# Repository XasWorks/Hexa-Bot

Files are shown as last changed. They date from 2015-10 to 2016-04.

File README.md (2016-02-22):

# Hexa-Bot

All required files, both .scad files for 3D Models aswell as the source files for the Arduino programming and the circuit plans for custom electronics (motor controller, special sensors, display etc.)

For documentation, see the "documentation" folder. Most importantly the scematics can be found under "KiCAD".

To program a robot, open Eclipse with working AVR Plugin, and "import existing project", with the folder being EclipseWS/Zephyr_Functional
The used PORTS can be changed inside the Code/System/Robot.h file.

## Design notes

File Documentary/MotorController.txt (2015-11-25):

Motor Controller Documentation: 

Chips used:
    - ATMega328 MCU
    - Pololu A4988 Stepper Motor Driver

I2C Interface Layout: 
    - Ground (Black)
    - SDA (White)
    - Vcc (Grey)
    - SCL (Purple)

Ground Connections: 
    + SPI Connector 
    + Quartz    
    + MCU
    + I2C
    + Battery Connector
    + Driver.0 
    + Driver.1 
    + Driver.2
    
Vcc Connections: 
    + SPI 
    + MCU
    + I2C
    + Motor Drivers

Other connections:
    + Vmot 
    + Crystal
    + SPI Interface
    + I2C 
    + Microstepping pins
    + Sensor pins
    + Motor Controllers to MCU

Wiring from the Mega8: 
    - PB3 & PB4 & PB5: SPI
    - PB6 & PB7: OSC (16MHz)
    - PC0 - PC3: Sensor Connectors
    - PC5 & PC4: I2C Interface
    - PC6: RESET
    - PD0 & PD1: Driver.0
    - PD2 & PD3: Driver.1
    - PD4 & PD5: Driver.2

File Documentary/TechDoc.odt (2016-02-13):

Technische Dokumentation des Roboters „Zephyr“ - RoboCup 2016

Teammitglieder: David Bailey, Felix Diekmann

Steuergerät:

Das Steuergerät des Roboters ist ein auf dem ATMega328-P basierendes, selbst gebautes Controller-Board. Der MCU läuft auf 16 Mhz, und wird mithilfe eines STK500v2 über SPI programmiert.

Ebenfalls auf dem Board befindlich ist ein 5v Spannungsregler zur Stromversorgung, Anschlüsse für vier Sensoren (analog/digital), sowie drei Pololu A4988 Stepper Motor Treiber zur Steuerung der Schrittmotoren, wobei das Microstepping über einige Schalter angepasst werden kann. Zusätzlich können weitere Module mithilfe von TWI (bzw. I2C) angeschlossen werden.

Sensorik:

Die Sensorik des Roboters besteht aus drei DFRobot SEN0017 Digital Line Tracking Sensoren, sowie einem Endstop Switch.

Die Line Tracking Sensoren wurden am vordere Ende des Roboters angebracht und dienen dem Line-Following. Sie sind direkt am Controller-Board angeschlossen, und liefern digitale Daten über das (nicht) vorhanden sein der Linie an der jeweiligen Position.

Der Endstop Switch ist oberhalb der Line Tracking Sensoren angebracht, und dient der Erkennung von Hindernissen, um diese umgehen zu können.

Aktuatorik:

Die Aktuatorik des Roboters besteht aus drei in 120° voneinander gedrehten Positionen angebrachten Schrittmotoren (2x Pololu 35x36mm, 2.7V, 1A / Phase, 1x Pololu 35x26mm, 7.4V, 0.28A / Phase), an denen eigens erstellte und 3D gedruckte Omni-Wheels angebracht wurden. Sie werden über die auf dem Controller-Board befindlichen Stepper Motor Controller mit Strom versorgt und gesteuert.

Als Motor für den Greifarm wird ein HobbyKing HK15148B Digital Servo verwendet.

Software:

Die Software für den ATMega328-P wurde komplett in C++ geschrieben, und verwendet ausschließlich eigene, speziell für den Roboter geschriebene Bibliotheken. Als IDE dient Eclipse Luna mit AVR Plugin, um kompilieren mit dem AVR-GCC Compiler zu ermöglichen. Als VCS dient Github ( https://www.github.com/Xasin/Hexa-Bot )

Die 3D-Modellierung aller Teile ist mit OpenSCAD geschehen. Auch hier wurde einzig selbst geschriebener Code verwendet.

Spezielle Hinweise:

Aktuatorik:

Die spezielle Aktuatorik des Roboters, bestehend aus den drei in 120°-Winkeln angeordneten Schrittmotoren, erlaubt für einen zentimetergenauen omnidirektionalen Antrieb. Dieser erlaubt es dem Roboter, sich komplett frei auf einer zweidimensionalen Oberfläche zu bewegen und sich problemlos zu Drehen, vorwärts/rückwärts und seitwärts zu fahren.

Dies macht das gesamte System sehr mobil und wendig, was viele Aufgaben, welche Präzision benötigen, einfacher gestaltet.

Software:

Um eine solche Bewegungsfreiheit voll ausnutzen zu können wurde die Software auf eine Art und Weise geschrieben, welches die Steuerung um ein vielfaches vereinfacht. Hierbei werden die einzelnen Schrittmotoren jeweils von einem eigenen Objekt angesteuert, welches über einen 5kHz ISR eine simple Geschwindigkeitssteuerung bietet und für einen ruhigen Lauf sorgt. Diese simplen Schrittmotor-Objekte werden von einer Controllsoftware mit ca. 150Hz angesteuert. Diese komplexere Software übernimmt die Berechnung von X und Y Geschwindigkeit um eine konstante lineare Geschwindigkeit zu realisieren, und speichert dabei die momentane Position ab, welche sie mit der Soll-Position vergleichen kann.

Dies erlaubt es dem Benutzer die Motoren durch simple Angabe von X und Y Koordinaten in Millimeter, bzw. Rotation in Grad zu steuern, sowie Geschwindigkeiten in mm/s und Grad/s ein zu stellen.

Zudem wurde der Code so flexibel wie möglich strukturiert. Objekte wurden, wenn möglich, verwendet.

So z.B. gibt es eine bestimmte Klasse, welche nur für die Verwertung der Line Tracking Sensoren verwendet wird. Sie basiert auf einer Base-Klasse, und wird lediglich durch Pointer in anderen Objekten und Funktionen verwendet. Dies erlaubt es, schnell und ohne viel Mühe einen anderen Sensortyp ein zu bauen. Lediglich ein anderes Objekt muss instanziert und übergeben werden.

Auch in der Main-Loop wird dort lediglich die Funktion eines Pointers zu einem bestimmtem Objektes ausgeführt. Dieser Pointer kann dann während einer ISR umgeändert werden, sodass nun ein anderer Code ausgeführt wird. Dies erlaubt eine sehr flexible und verständliche Struktur, da jede Funktion eine bestimmte Aufgabe übernehmen kann, ohne dabei andere Funktionen zu beeinflussen.

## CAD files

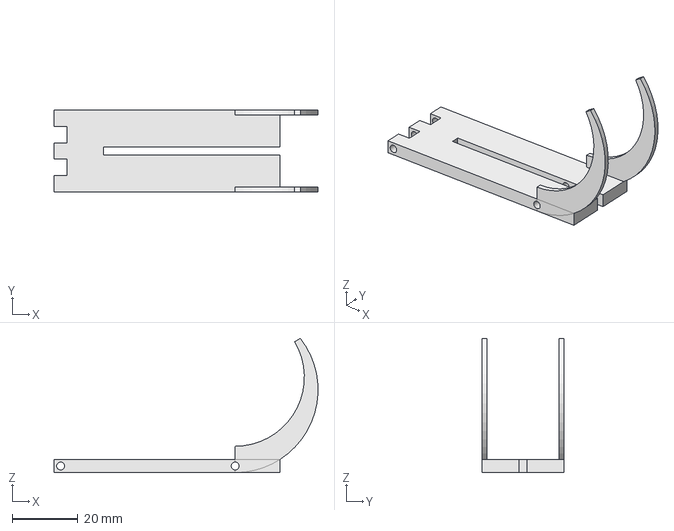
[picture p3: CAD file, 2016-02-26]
3DModels/GrabArm/MainArm.fcstd
80.1 x 25.0 x 40.7 mm

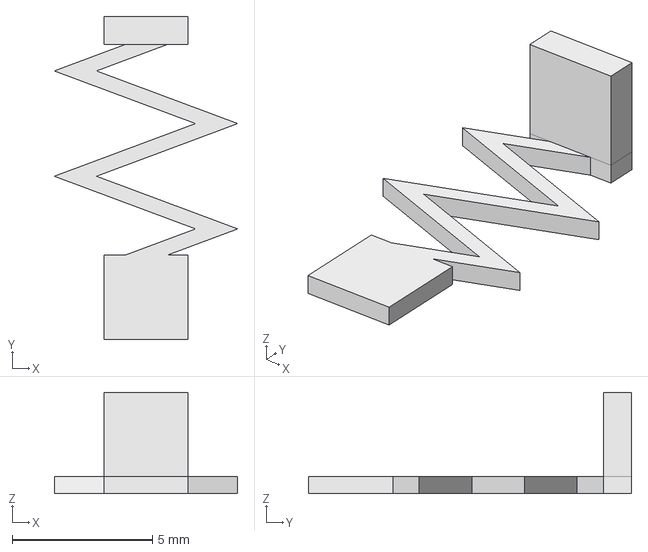
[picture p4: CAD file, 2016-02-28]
3DModels/GrabArm/MoveSpring.fcstd
6.53 x 11.5 x 3.60 mm

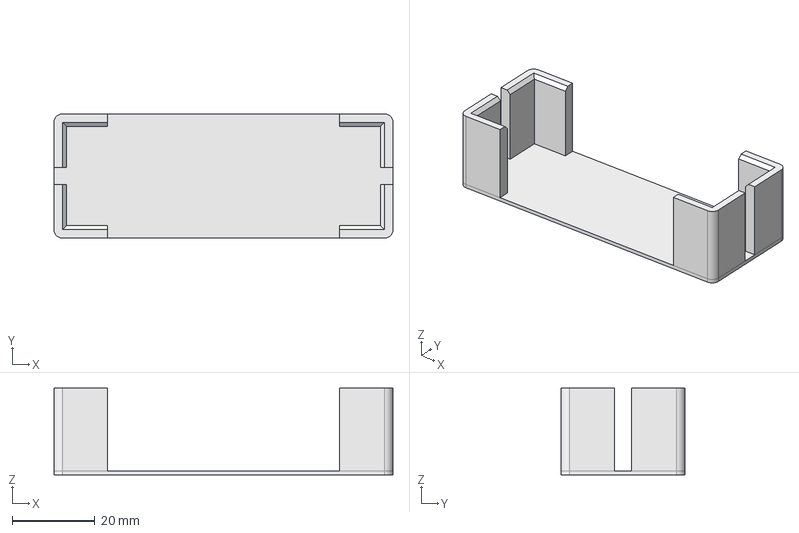
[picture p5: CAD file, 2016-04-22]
3DModels/HexGridSystem/BatteryHolder/BHolder.fcstd
82.0 x 30.0 x 21.0 mm

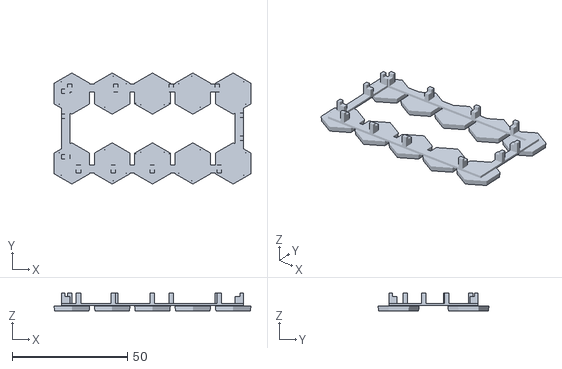
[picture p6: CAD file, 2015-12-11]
3DModels/STL/ControllerHolder.stl
85.5 x 48.2 x 7.75

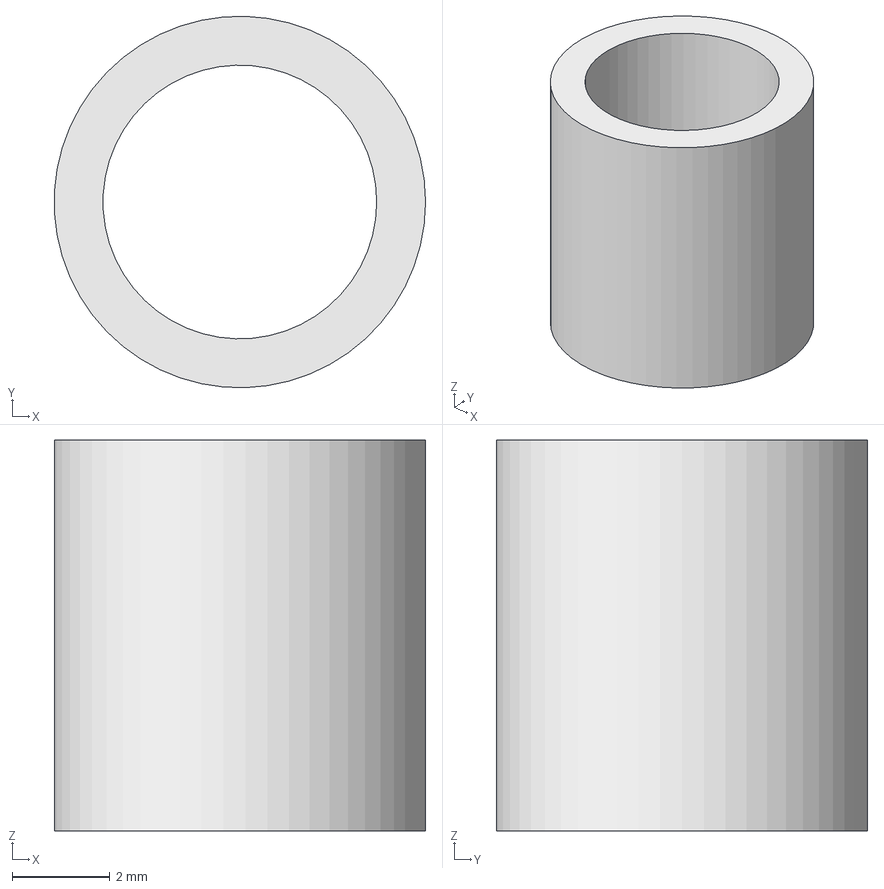
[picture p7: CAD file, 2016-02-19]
3DModels/Various/WheelDistancer.fcstd
7.59 x 7.60 x 8.00 mm

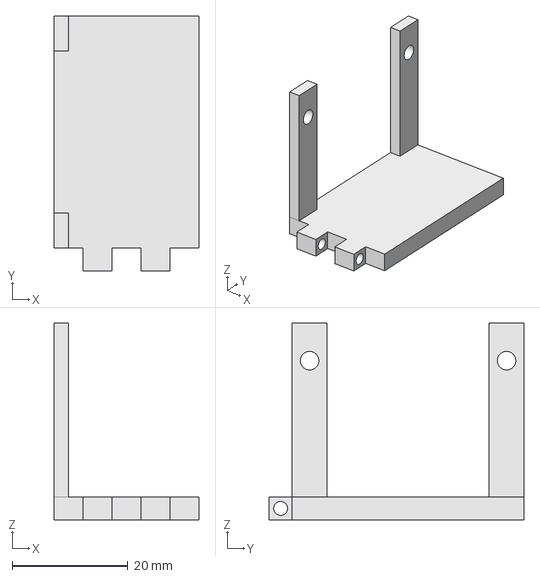
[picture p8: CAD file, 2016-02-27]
3DModels/GrabArm/Mountpoint.fcstd
25.0 x 44.0 x 34.0 mm

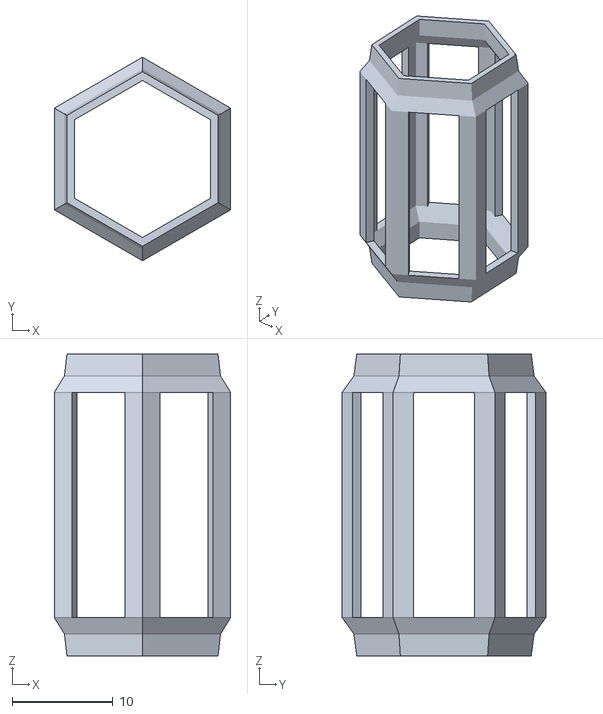
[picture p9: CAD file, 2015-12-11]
3DModels/STL/Distancer.stl
17.5 x 20.2 x 30.0

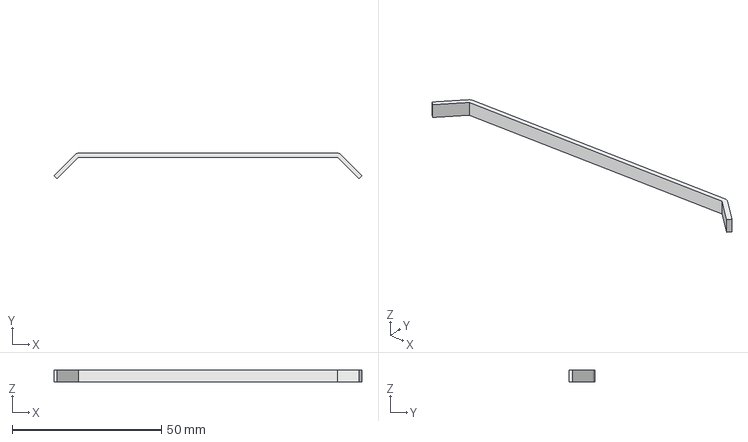
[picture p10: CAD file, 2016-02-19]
3DModels/Various/Bumper.fcstd
103.3 x 8.57 x 4.00 mm

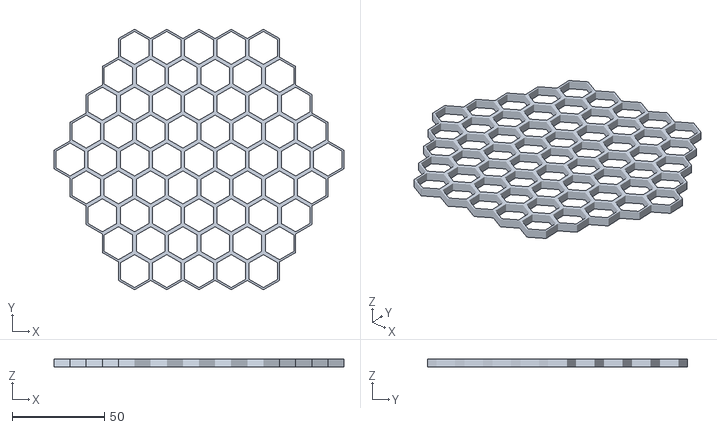
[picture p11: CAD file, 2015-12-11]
3DModels/STL/BasePlate.stl
157.5 x 141.5 x 4.40

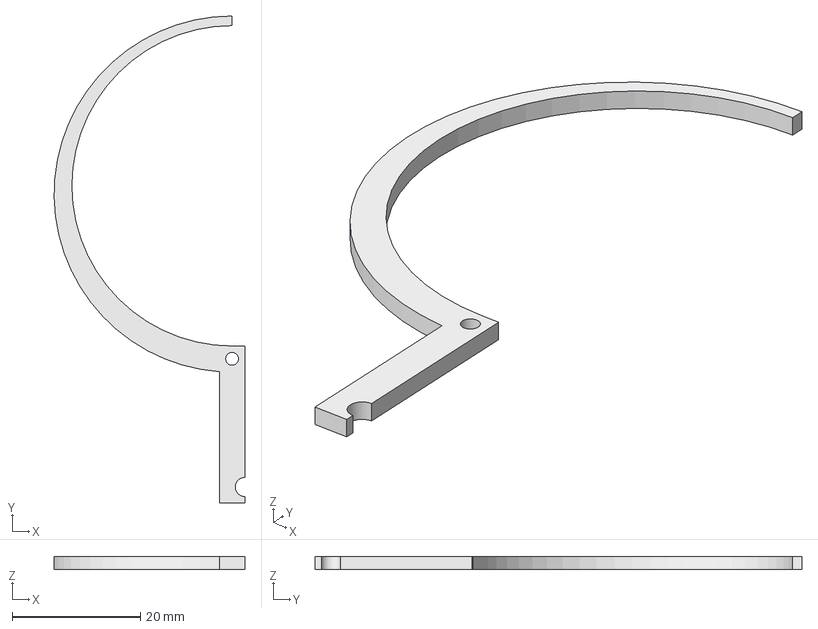
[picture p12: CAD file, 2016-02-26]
3DModels/GrabArm/MoveArm.fcstd
29.8 x 76.0 x 2.00 mm

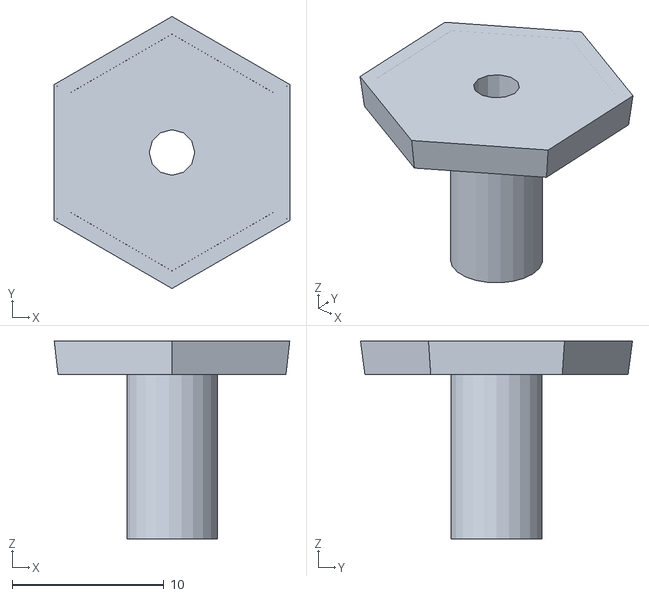
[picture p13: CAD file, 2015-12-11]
3DModels/STL/LF-Senor-Mount.stl
15.5 x 17.9 x 13.0

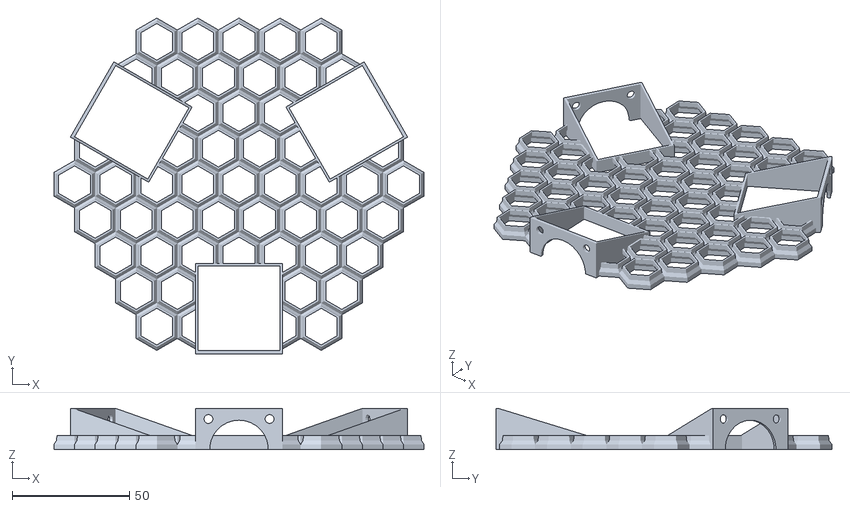
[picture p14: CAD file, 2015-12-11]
3DModels/STL/MotorPlate.stl
157.5 x 143.0 x 17.5

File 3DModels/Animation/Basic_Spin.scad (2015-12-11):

use <../Lib/Parenting.scad>
use <../Lib/HexGrid.scad>

//function linearSegmet(start, end, v1, v2) = if($t < start) v1 else if($t > end) v2 else (($t - start) / (end - start)) * (v2 -v1) + v1;
function linearSegmet(start, end, v1, v2) = ($t < start) ? (v1) : ( ($t > end) ? v2 : ( (($t - start) / (end - start)) * (v2 -v1) + v1 ));
function linearLift(start, end, v1, v2) = [[0, 0, linearSegmet(start, end, v1, v2)], 0];
function segmentedLift(n, i, v1, v2) = linearLift(i/n, (i+1)/n, v1, v2);

module electronicsMount() color("Orange"){
  translate([17.5/2, 0, 2.2 + 1]) import(file = "../STL/ControllerHolder.stl");
}

module basePlate() color("YellowGreen") {
  import(file = "../STL/BasePlate.stl");
}

top_layer_node = [[0, 0, 30 - 2.2], [0, 0, 0]];
module distancerModules() color("orange") {
  translate([0, 0, -3.8])
  for (i = [0:5]) {
    rotate([0, 0, 60*i])
    parentBy(hexNode([4, 0]))
    import(file = "../STL/Distancer.stl");
  }
}

module LF_Sensor() color("Orange") {
  translate([0, 0, -13 + 2.2]) import(file = "../STL/LF-Senor-Mount.stl");
}

module motorPlate() color("YellowGreen") {
  translate([0, 0, 6]) rotate([180, 0, 0]) import(file = "../STL/MotorPlate.stl");
}

splitDistance = $t * 4;

//Node for the robot's ground position
ground_node = [[0, 0, 0], [0, 0, 0]];

//Additional node for animation distancing
split_node = [[0, 0, splitDistance], [0, 0, 0]];

totalSegments = 3;

$vpr = [70, 0, linearSegmet(0, 1, 120, -5)];

parentBy(ground_node) {

  motorPlate();

  parentBy(hexNode([3, 1]) + linearLift(0, 0.3, 100, 0) ) LF_Sensor();
  parentBy(hexNode([2, 3]) + linearLift(0, 0.3, 100, 0) ) LF_Sensor();

  parentBy(hexNode([0,0])) {
    parentBy(linearLift(0.1, 0.4, 100, 0)) distancerModules();

    parentBy(top_layer_node) {
      parentBy(linearLift(0.2, 0.5, 100, 0)) basePlate();

      parentBy(hexNode([-1, -3], 2.2) + linearLift(0.3, 0.6, 100, 0)) electronicsMount();
    }
  }
}

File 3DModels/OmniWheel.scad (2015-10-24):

/*
	.scad file created for the subwheel system of the 3D Printable Omni-Wheels used for a robot.
	
	
	Author 	= Xasin
	Website = https://www.github.com/xasin/hexa-bot.git
	Created	= 17.09.15
*/

use <Transforms.scad>

function subwheelRadius(n, r) = r - cos(360/(2*n) + subwheelOverlap)*r + subwheelBaseSize;		//Calculate the radius of a standard subwheel at largest point (Center)
function wheelOffset(n, r) = cos(360/(2*n) + subwheelOverlap)*r;						//Calculate the offset of a subwheel that is required to shift it so that it aligns with the main circle (CAUTION Does not implement subwheel size shift!!)
function connectorOffset(n, r) = (sin(360/(2*n) + subwheelOverlap)*r);					//Calculate the offset for the cuts on the wheels. (Y axis on the 2D model of a subwheel before being rotated.
	
$fs = 0.5;

//What to generate - 1 means base frame, 2 means subwheel piece
generate = 1;

//GENERATION VARIABLES 
num = 5*2;	//Number of all subwheels to create. (Has to be a round number!!)
radius = 20;	//Radius of the omni-wheel.

//SUBWHEEL VARIABLES
subwheelBaseSize = 3.5;	//Size of the subwheels at their smallest point (The edge)
subwheelPlay = 0.5; 		//The additional size that will be cut out around the subwheels to ensure smooth movement
subwheelOverlap = 3;		//Angle in which the subwheel pieces will overlap. Causes smoother movement as there is no definite edge.

//AXIS HOLE VARIABLE
axisDiameter = 1.75;
axisPlay = 0.383;

//SUBWHEEL CONNECTOR VARIABLES
cRad = axisDiameter/2 + 1.5; 	//Radius of the connectors to the subwheels (Best is slightly smaller than the subwheel.
cThick = 0.8; 					//Thickness of the connectors.
cPlay = 0.2; 					//Play room for the connector ports (distance to the subwheel)

//FRAME VARIABLES
frameRadius = connectorOffset(num, radius) + cPlay + cThick;		//Radius of the frame Cylinder
frameHeight = cRad + subwheelRadius(num, radius);
frameThickness = 0.8;		//Thickness of the main frame

//STABILITY BEAM VARIABLES
beamThickness = 2.5; 		//Thickness of the stability beams
beamNum = 5;

//CONNECTOR VARIABLES
connectorThickness = 1;	//Thickness of the vertical connectors
connectorInShift = 0.4;		//Inwards shift of the vertical connector beams (for smoother connection)
connectorHeight = 2.5;		//Height of the connector pieces above the main frame.

module subwheelBase(n, r=20, p=0, shift = subwheelBaseSize, split=true, positioned=true) {  //The base structure of a Subwheel, basically a slice of a circle of the radius of the wheel, cut down to be rotated into a proper subwheel for a wheel of Radius R with N Subwheels.
	
	//Position the wheel according to the given parameters (Aling it to the outside of the main wheel and rotate it around into position p.)
	render(4) if(positioned) {
		//Rotate to the according outside position.
		rotate([0, 0, (360/n) * p])
		//Translate to the edge of the circle
		translate([ wheelOffset(n, r) - subwheelBaseSize, 0, 0])
		//Rotate into horizontal position
		rotate([-90, 0, 0]) 
		//The main core of the subwheel
		subwheelBase(n, r, p, shift, split, false);
	}
	//Generate a standard subwheel without moving it around.
	else {
		render(convexity=4) difference() {				//Render the subwheel and make it hollow.
			union() {
				rotate_extrude() difference() {		//Generate the main subwheel
					intersection() {					//2D Model for the basic subwheel
						translate([ - wheelOffset(n, r) + shift, 0]) circle(r=r, $fn = 70);		//Main circle	
						translate([0, - sin(360/(2*n) + subwheelOverlap)*r]) square(sin(360/(2*n) + subwheelOverlap)*r *2);			//Intersecting square to only have the desired part of the circle
					}	
						
				}
				translate([0, 0, - sin(360/(2*n) + subwheelOverlap)*r]) cylinder(r=shift, h= sin(360/(2*n) + subwheelOverlap)*r *2);	//Central cylinder inside for the axis.
			}
			
			if(split) {
				translate([0,0,-(sin(360/(2*n) + subwheelOverlap)*r)]) cylinder(d= axisDiameter + axisPlay*2, h= 2* sin(360/(2*n) + subwheelOverlap)*r,$fn=15);	//Slot for the Filament-Axis, rolling
			}
		}
	}
}

//Create the connecting beams for the subwheels
module subwheelConnector(n, r, i) {
	render(convexity = 3)
	rotate([0,0, (360/n)*i]) 
	difference() {				//The difference cuts the hole for the axis into the connectors
		intersection() {		//The intersection makes sure that the subwheel connectors don't poke outside of the wheel radius. This should not be nececary, but for smaller subwheel base sizes might be desirable.
			union() {		//The cylinders here are the end cylinders on either side of the connector, the cubes are the beams that connect those cylinders to the main frame.
				translate([wheelOffset(n, r) - subwheelBaseSize, connectorOffset(n, r) + cPlay + cThick]) rotate([90, 0, 0]) cylinder(r= cRad, h= cThick, $fn = 13);		
				
				translate([0, connectorOffset(n, r) + cPlay, -cRad]) 
					cube([wheelOffset(n, r) - subwheelBaseSize, cThick, cRad*2]);
				
				translate([wheelOffset(n, r) - subwheelBaseSize, -connectorOffset(n, r) - cPlay]) rotate([90, 0, 0]) cylinder(r= cRad, h= cThick, $fn = 13);
						
				translate([0, -connectorOffset(n, r) - cPlay - cThick, -cRad]) 
					cube([wheelOffset(n, r) - subwheelBaseSize, cThick, cRad*2]);
			}
			
			translate([0,0, -cRad]) cylinder(r=r - 0.3, h= cRad*2);
		}
		
		translate([wheelOffset(n, r) - subwheelBaseSize, connectorOffset(n, r) + 5, 0]) rotate([90,0,0]) cylinder(d= axisDiameter + 0.4, h= connectorOffset(n, r)*2 + 10, $fn=14);
	}
}

module connectorStrengthener(n, r, i) {
	rotate([0,0, 360/n * i]) translate([0,0, -cRad]) intersection() {
		cylinder(r=sqrt(pow(connectorOffset(n, r),2) + pow(wheelOffset(n, r) - subwheelBaseSize, 2)) + 0.6, h=0.8, $fn=75);
		translate([0,connectorOffset(n, r) + cPlay,0]) cube([r, r, 0.8]);
		rotate([0,0, 360/n*2]) translate([0,-(connectorOffset(n,r) + cPlay + r), 0]) cube([r,r, 0.8]);
	}
}

//Create a set of subwheels as they would be normally positioned. Inflated = true makes them bigger; useful for creating space around the wheels.
module subwheelSet(n, r, inflated=false) {
	for(i=[0:2:n]) { 	
		if(inflated) {		
			subwheelBase(n, r, i, shift = subwheelBaseSize + subwheelPlay, split=false);									//Create a /bigger/ subwheel in normal, ground position.
		}
		else {
			subwheelBase(n, r, i);									//Do the same as above, however using default subwheels instead of bigger subwheels here.
		}
	}
}

//Create a subwheel connector set for the according wheel of size r with n subwheels.
module connectorSet(n, r) {
	for(i=[0:2:n]) {
		subwheelConnector(n, r, i);
		connectorStrengthener(n, r, i);
	}
}

//Create the central cylinder piece.
module centralCylinder(n, r) {
	render(convexity = 4) translate([0,0, - cRad]) difference() {
		cylinder(r= frameRadius, h= frameHeight);		//Create the central cylinder.
		cylinder(r= frameRadius - frameThickness, h= frameHeight);	//Hollow it out
	}
}
		
//Create the pieces that connect the two Omniwheel pieces together
module interconnectorPiece(n, r) {
	difference() {
		shine(height= frameHeight + connectorHeight, angle=(360/n) - 0.5, length= r)
		//"Shine" is a custom function that cuts down an object to a specific angle
		union() {
			cylinder(r= frameRadius - 0.1, h= frameHeight);		//Cylinder piece to connect the connector to the main frame.
			cylinder(r= frameRadius - frameThickness - connectorInShift, h= frameHeight + connectorHeight);		//Cylinder piece for the actual interconnector. This one is slightly smaller due to printing imperfections, thusly making sure that the pieces fit together nicely.
		}
		cylinder(r= frameRadius - frameThickness - connectorThickness - connectorInShift, h= frameHeight + connectorHeight);		//Hollow the interconnection pieces out so that they have the correct thickness.
		
	}
}

//Create the interconnections between two wheel pieces
module interconnections(n, r) {
	render(convexity= 2) translate([0,0, -cRad])
		for(i=[0:(360/(n/2)):360]) 
			rotate([0,0, i + 360/n])											
			interconnectorPiece(n, r);	
}

//Create the structural beams inside the subwheel for better stability.
module structuralBeams() {
	render(convexity = 4) translate([0,0, -cRad]) intersection() {
		cylinder(r= frameRadius, h= cRad*2);		//Make sure that the structural beams don't poke out of the main frame.
		
		for(i=[0:360/beamNum:360]) 
			rotate([0,0, i + 360/beamNum/2]) translate([0, -beamThickness/2, 0]) cube([frameRadius, beamThickness, 1]);		//Create the beams.
	}
}

//The Mainframe of the OmniWheel
module omniWheel(n, r, subwheels = false) {
	difference() {  union() {
			//Central Cylinder 
			centralCylinder(n, r);
			
			//Cylinder Interconnections

			interconnections(n, r);
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

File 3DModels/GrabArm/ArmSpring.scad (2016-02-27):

springLength = 20;

mntpadLength = 5;


cube([10, springLength, 1]);

cube([10, mntpadLength, 2]);
translate([0, springLength - mntpadLength, 0]) cube([10, mntpadLength, 2]);

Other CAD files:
3DModels/GrabArm/BallSpacer.scad
3DModels/GrabArm/Mountpoint.scad
3DModels/GrabArm/Mountpoint.stl
3DModels/GrabArm/MoveSpring.scad
3DModels/GrabArm/TestArm.scad
3DModels/HexGrid.scad
3DModels/HexGridSystem/BasePlate.scad
3DModels/HexGridSystem/BatteryHolder/Base.scad
3DModels/HexGridSystem/BoopSensor.scad
3DModels/HexGridSystem/ControllerHolder.scad
3DModels/HexGridSystem/Distancer.scad
3DModels/HexGridSystem/GreyscaleHolder.scad
3DModels/HexGridSystem/IR-Dist-Mount.scad
3DModels/HexGridSystem/LF-Sensor-Mount.scad
3DModels/HexGridSystem/LF-Sensor-Shielding.scad
3DModels/HexGridSystem/MotorPlate.scad
3DModels/HexGridSystem/SensorControllerHolder.scad
3DModels/HexGridSystem/SensorMount.scad
3DModels/HexGridSystem/StepperMotorHolder.scad
3DModels/Motion/OmniWheel.scad
3DModels/NewHexGrid.scad
3DModels/STL/Animation.scad
3DModels/Various/BSensorShielding.scad
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

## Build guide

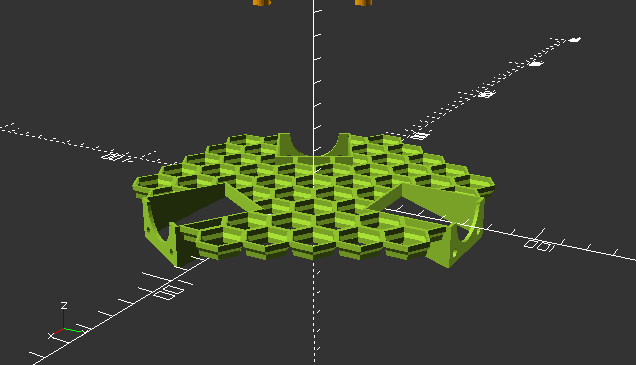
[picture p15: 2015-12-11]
3DModels/Animation/setup.gif

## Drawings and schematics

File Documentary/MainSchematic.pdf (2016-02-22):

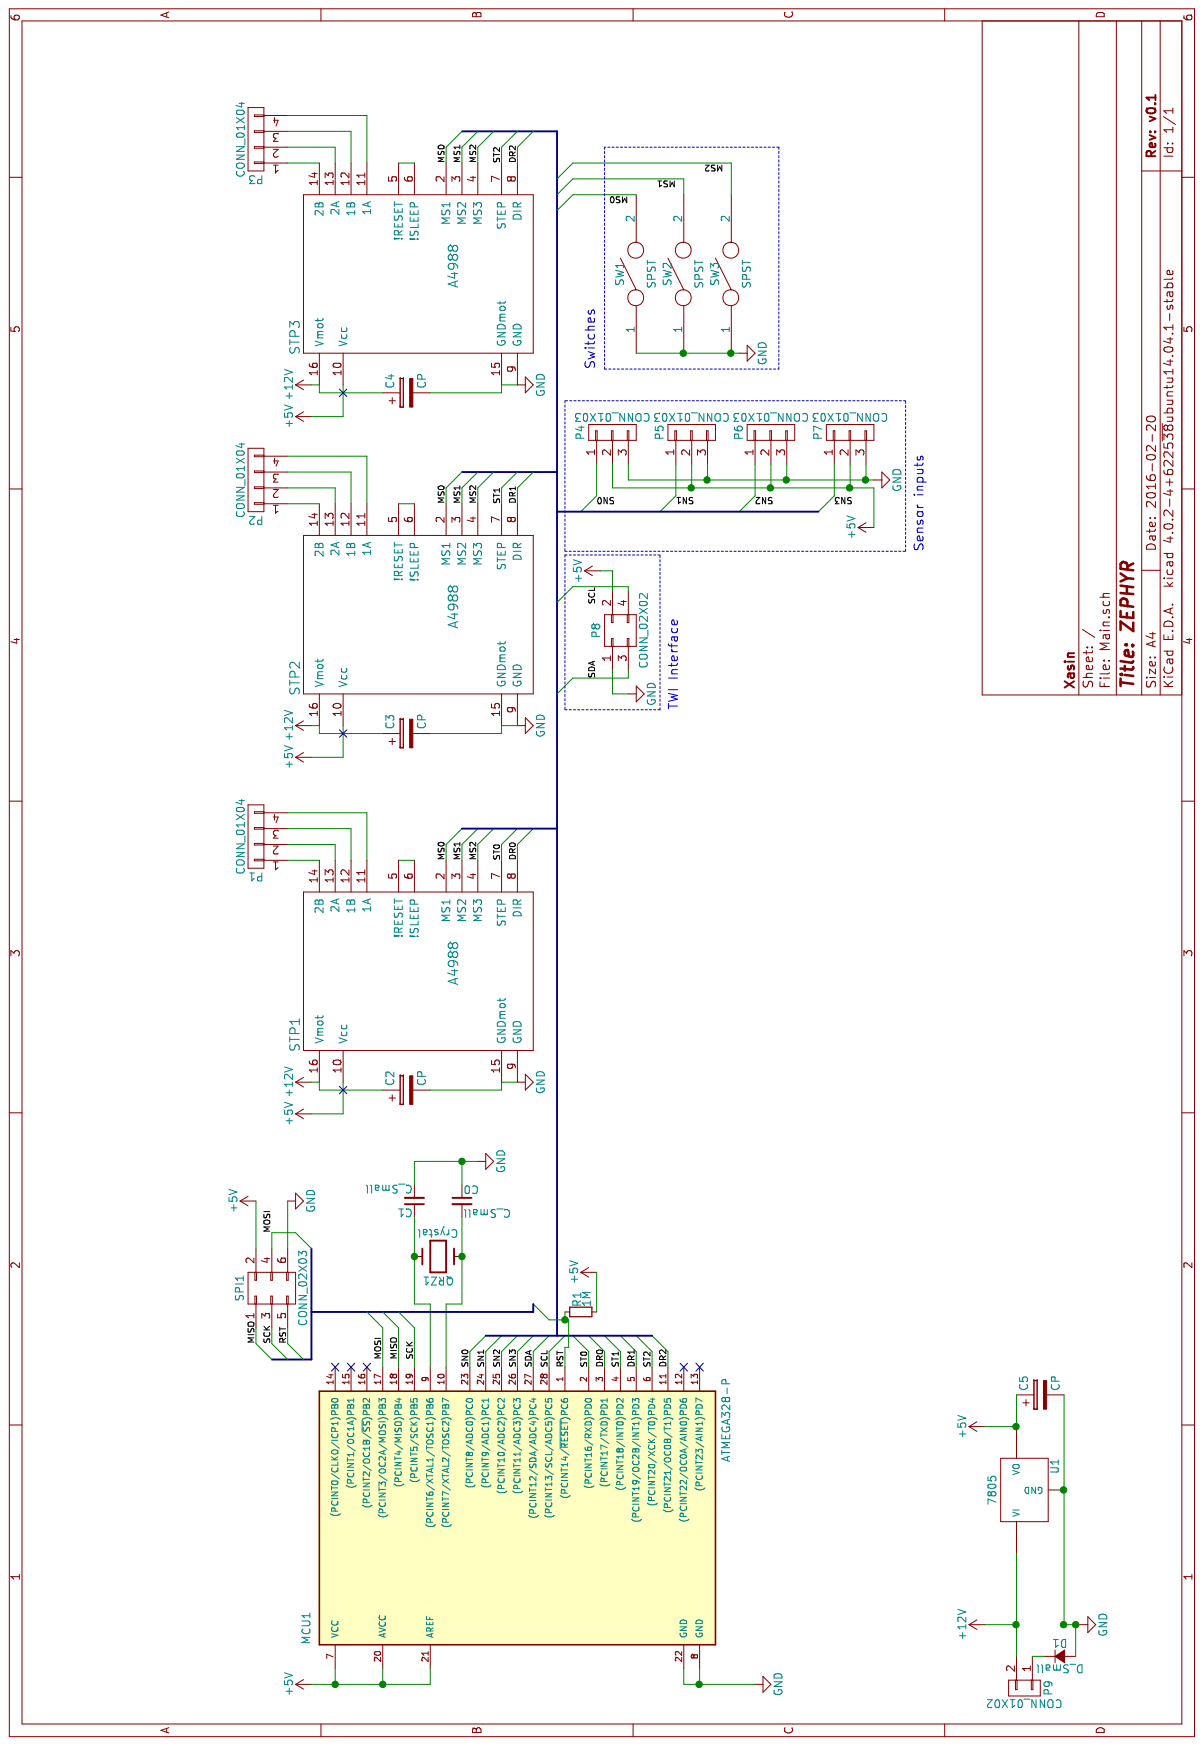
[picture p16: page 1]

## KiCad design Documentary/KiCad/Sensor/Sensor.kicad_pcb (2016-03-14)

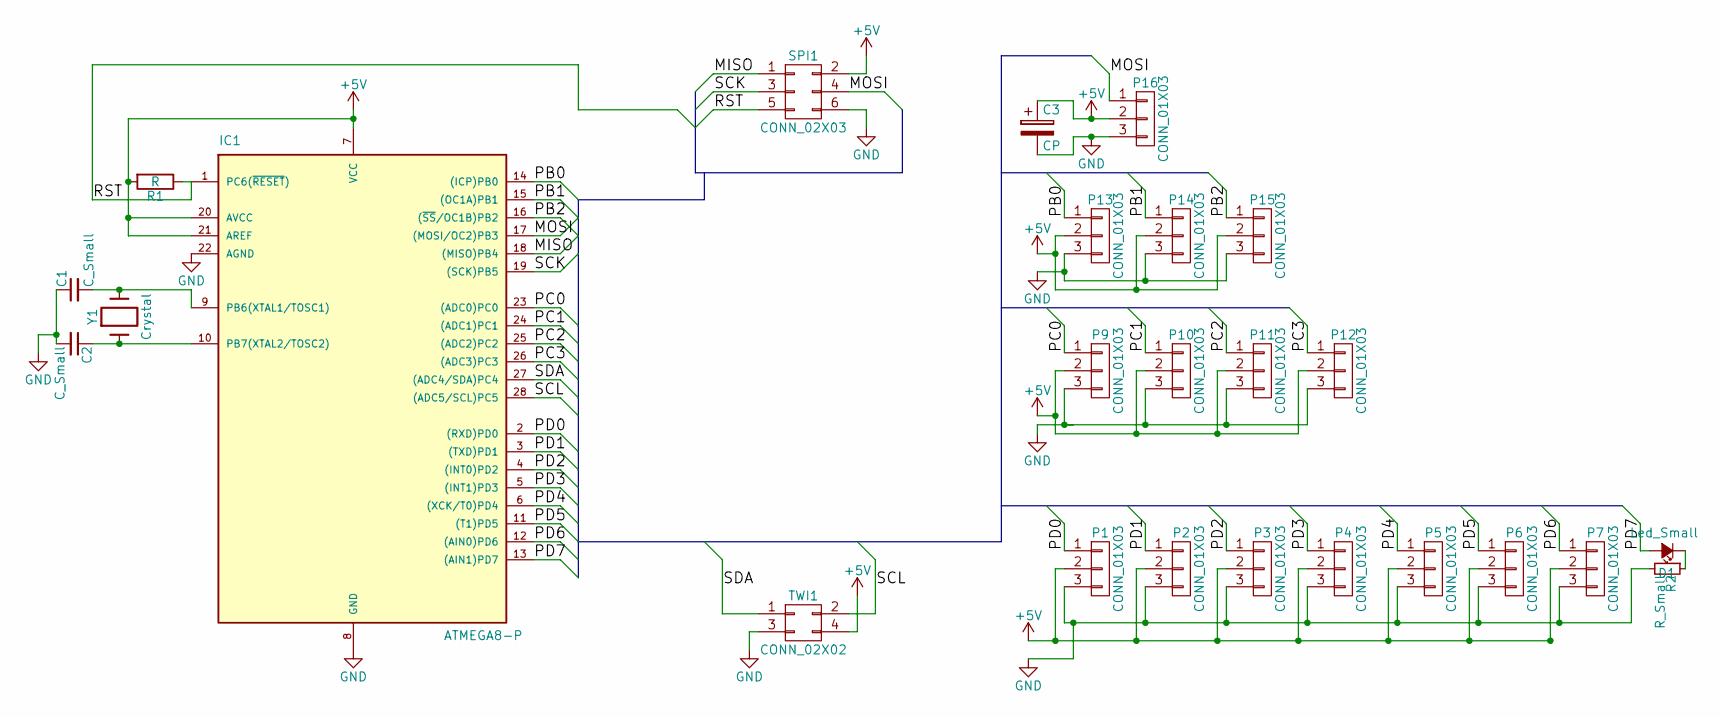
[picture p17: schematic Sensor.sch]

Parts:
C1, C2: C_Small; C_Disc_D3_P2.5
C3: CP; C1V8
D1: Led_Small; LED-3MM
IC1: ATMEGA8-P; DIP-28_W7.62mm
P1, P2, P3, P4, P5, P6, P7, P9, P10, P11, P12, P13, P14, P15, P16: CONN_01X03; Pin_Header_Straight_1x03
R1: R; R1
R2: R_Small; R1
SPI1: CONN_02X03; Pin_Header_Angled_2x03
TWI1: CONN_02X02; Pin_Header_Straight_2x02
Y1: Crystal; Crystal_HC52-U_Vertical

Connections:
+5V: C3.1, IC1.7 (VCC), IC1.20 (AVCC), IC1.21 (AREF), P1.2, P2.2, P3.2, P4.2, P5.2, P6.2, P7.2, P9.2, P10.2, P11.2, P12.2, P13.2, P14.2, P15.2, P16.2, R1.2, SPI1.2, TWI1.4
/MISO: IC1.18 ((MISO)PB4), SPI1.1
/MOSI: IC1.17 ((MOSI/OC2)PB3), P16.1, SPI1.4
/PB0: IC1.14 ((ICP)PB0), P13.1
/PB1: IC1.15 ((OC1A)PB1), P14.1
/PB2: IC1.16 ((~SS~/OC1B)PB2), P15.1
/PC0: IC1.23 ((ADC0)PC0), P9.1
/PC1: IC1.24 ((ADC1)PC1), P10.1
/PC2: IC1.25 ((ADC2)PC2), P11.1
/PC3: IC1.26 ((ADC3)PC3), P12.1
/PD0: IC1.2 ((RXD)PD0), P1.1
/PD1: IC1.3 ((TXD)PD1), P2.1
/PD2: IC1.4 ((INT0)PD2), P3.1
/PD3: IC1.5 ((INT1)PD3), P4.1
/PD4: IC1.6 ((XCK/T0)PD4), P5.1
/PD5: IC1.11 ((T1)PD5), P6.1
/PD6: IC1.12 ((AIN0)PD6), P7.1
/PD7: D1.2 (A), IC1.13 ((AIN1)PD7)
/RST: IC1.1 (PC6(~RESET~)), R1.1, SPI1.5
/SCK: IC1.19 ((SCK)PB5), SPI1.3
/SCL: IC1.28 ((ADC5/SCL)PC5), TWI1.2
/SDA: IC1.27 ((ADC4/SDA)PC4), TWI1.1
GND: C1.1, C2.2, C3.2, IC1.8 (GND), IC1.22 (AGND), P1.3, P2.3, P3.3, P4.3, P5.3, P6.3, P7.3, P9.3, P10.3, P11.3, P12.3, P13.3, P14.3, P15.3, P16.3, R2.2, SPI1.6, TWI1.3
unnamed: C1.2, IC1.9 (PB6(XTAL1/TOSC1)), Y1.2
unnamed: C2.1, IC1.10 (PB7(XTAL2/TOSC2)), Y1.1
unnamed: D1.1 (K), R2.1

Board: 2 copper layers, 25 parts (0 on the bottom side), 26 nets, no tracks yet.

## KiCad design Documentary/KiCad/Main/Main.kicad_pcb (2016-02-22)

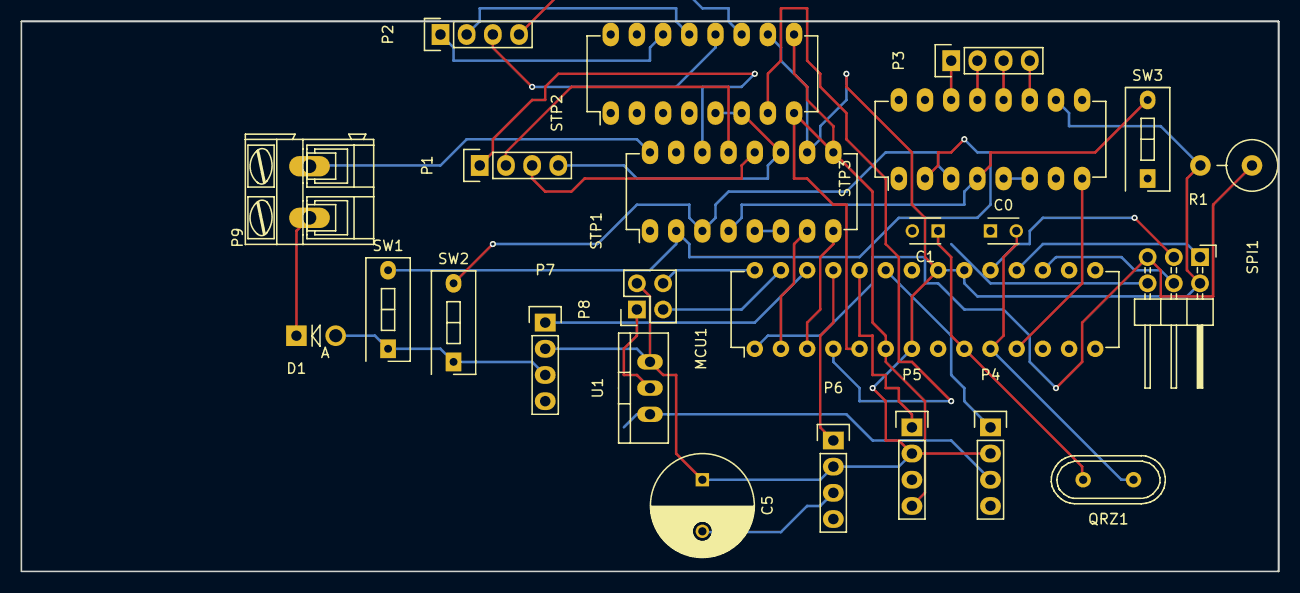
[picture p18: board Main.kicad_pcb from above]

Board: 32 copper layers, 121.9 x 53.3 mm, 24 parts (0 on the bottom side), 40 nets.

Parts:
C0, C1: C_Small; C_Disc_D3_P2.5
C5: CP; C_Radial_D10_L13_P5
D1: D_Small; Diode_DO-41_SOD81_Vertical_AnodeUp
MCU1: ATMEGA328-P; DIP-28_W7.62mm
P1, P2, P3: CONN_01X04; Pin_Header_Straight_1x04
P4, P5, P6, P7: CONN_01X03; Pin_Header_Straight_1x04
P8: CONN_02X02; Pin_Header_Straight_2x02
P9: CONN_01X02; AK300-2
QRZ1: Crystal; Crystal_HC49-U_Vertical
R1: 1M; Resistor_Vertical_RM5mm
SPI1: CONN_02X03; Pin_Header_Angled_2x03
STP1, STP2, STP3: A4988; DIP-16_W7.62mm_LongPads
SW1, SW2, SW3: SPST; SW_DIP_x1_Slide
U1: 7805; TO-220_Neutral123_Vertical

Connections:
+5V: C5.1, MCU1.7, MCU1.20, MCU1.21, P4.2, P5.2, P6.2, P7.2, P8.2, R1.2, SPI1.2, STP1.10, STP2.10, STP3.10, U1.3
+12V: P9.2, STP1.16, STP2.16, STP3.16, U1.1
/DR0: MCU1.3, STP1.8
/DR1: MCU1.5, STP2.8
/DR2: MCU1.11, STP3.8
/MISO: MCU1.18, SPI1.1
/MOSI: MCU1.17, SPI1.4
/MS0: STP1.2, STP2.2, STP3.2, SW1.2
/MS1: STP1.3, STP2.3, STP3.3, SW2.2
/MS2: STP1.4, STP2.4, STP3.4, SW3.2
/RST: MCU1.1, R1.1, SPI1.5
/SCK: MCU1.19, SPI1.3
/SCL: MCU1.28, P8.4
/SDA: MCU1.27, P8.3
/SN0: MCU1.23, P4.1
/SN1: MCU1.24, P5.1
/SN2: MCU1.25, P6.1
/SN3: MCU1.26, P7.1
/ST0: MCU1.2, STP1.7
/ST1: MCU1.4, STP2.7
/ST2: MCU1.6, STP3.7
GND: C0.1, C1.2, C5.2, D1.2, MCU1.8, MCU1.22, P4.3, P5.3, P6.3, P7.3, P8.1, SPI1.6, STP1.9, STP1.15, STP2.9, STP2.15, STP3.9, STP3.15, SW1.1, SW2.1, SW3.1, U1.2
unnamed: C0.2, MCU1.10, QRZ1.1
unnamed: C1.1, MCU1.9, QRZ1.2
unnamed: D1.1, P9.1
unnamed: P1.1, STP1.14
unnamed: P1.2, STP1.13
unnamed: P1.3, STP1.12
unnamed: P1.4, STP1.11
unnamed: P2.1, STP2.14
unnamed: P2.2, STP2.13
unnamed: P2.3, STP2.12
unnamed: P2.4, STP2.11
unnamed: P3.1, STP3.14
unnamed: P3.2, STP3.13
unnamed: P3.3, STP3.12
unnamed: P3.4, STP3.11
unnamed: STP1.5, STP1.6
unnamed: STP2.5, STP2.6
unnamed: STP3.5, STP3.6

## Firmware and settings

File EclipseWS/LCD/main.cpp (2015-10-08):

/*
 * main.cpp
 *
 *  Created on: Oct 3, 2015
 *      Author: xasin
 */

#include <avr/io.h>
#include <util/delay.h>
#include <avr/interrupt.h>
#include <math.h>

#include "Code/LCD.h"
#include "PWMLed.h"

LCD disp(&PORTA);			//Create a new display object for the system.

PWMLed light1(&PORTD, 3, 20);
PWMLed light2(&PORTD, 0, 200);


volatile uint32_t ms=0;		//Millisecond-Counter variable.

volatile uint8_t pwm1 = 0;	//PWM Variable (contains counter and upper limit)
volatile uint8_t trg1 = 0;	//PWM "target" (to switch LED on and off)

volatile uint8_t splitter=0;	//Variable for the software prescaler for the interrupt.

ISR(TIMER1_COMPA_vect) {
	disp.updateDisplay();
	if(ms != 0)
		ms++;

	light1.updatePWM();
	light2.updatePWM();
}


int main() {
	PORTB |= (1<<0 | 1<<1);

	TCCR1B |= ((1<< CS11) | (1<< CS10) | (1<< WGM12));
	OCR1A =	F_CPU/64/1000 -1;

	TIMSK1 |= (1<< OCIE1A);

	sei();

	disp.cursorMode(CURSOR_ON_BLINK);

	//State of the light. 0 means completely off, 1 means awake, 2 means asleep
	uint8_t lightState = 0;
	uint8_t oldPinState = PINB & (0b00000011);
	while(true) {
		if(oldPinState != (PINB & 0b00000011)) {
			oldPinState = PINB & 0b00000011;
			switch(lightState) {
			case 0:
				if((PINB & (1<<1)) == 0)
					lightState = 1;
			break;
			case 1:
				if((PINB & (1)) == 0) {
					light2.setPWM(10);
					light1.setPWM(0);

					if((PINB & (1<<1)) == 0) {
						lightState = 2;
						light2.setPWM(0);
					}
				}
				else {
					light2.setPWM(0);
					light1.setPWM(13);

					if((PINB & (1<<1)) == 0) {
						light1.setPWM(0);
						lightState = 0;
					}
				}
			break;

			case 2:
				if(((PINB & 1) != 0) || ((PINB & (1<<1)) == 0)) {
					lightState = 1;
				}
			}
		}
	}
}

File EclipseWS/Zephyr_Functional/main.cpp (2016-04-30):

#include <avr/io.h>
#include <avr/interrupt.h>
#include <util/atomic.h>
#include <util/delay.h>

#include "Code/ADC/ADC_Lib.h"

#include "Code/System/Robot.h"
#include "Code/LineFollow/LF3Sens.h"

#include "Code/TWI/TWIHandler.h"
#include "Code/TWI/TWIJob.h"

#include "Code/Modules/LFFollow.h"
#include "Code/Modules/Intersection.h"
#include "Code/Modules/ObjectAvoid.h"

#include "Module/BallFineGrab.h"

#include "ServoController.h"
#include "IRDistanceSensor.h"
#include "BrightnessSensor.h"

Robot System = Robot();
LF3Sens LFSensor = LF3Sens();

ServoController servo = ServoController();
IRDistanceSensor irdist = IRDistanceSensor();
BrightnessSensor brsens = BrightnessSensor();

using namespace Module;
LFFollow LFSys = LFFollow(&System, &LFSensor);
Intersection INTSECSys = Intersection(&System, &LFSensor);
ObjectAvoid AVDSys = ObjectAvoid(&System);

BallFineGrab GRABSys = BallFineGrab(&System, &irdist, &servo);

Basic *cModule;

ISR(TWI_vect) {
	TWI_Handler::IO.update();
}

ISR(TIMER1_COMPA_vect) {
	System.update();

	LFSensor.update();
}

#define TASK_LF 	0
#define TASK_INTSEC 1
#define TASK_OBJ 	2

uint8_t currentTask = TASK_LF;

void setTask() {
	switch(currentTask) {
		// -- STANDARD LF --
		case TASK_LF:

			// Switch to object avoidance mode
			if((PINC & (1<< 3)) == 0) {
				irdist.updateWaiting();
				AVDSys.distance = irdist.get_distance();
				AVDSys.execute();
			}

			// Else, switch to Intersection mode
			else if ((LFSensor.lineStatus == LF_INTSEC)) {
				currentTask = TASK_INTSEC;
				cModule = &INTSECSys;
			}


		break;

		// -- INTERSECTION HANDLING --
		case TASK_INTSEC:
			currentTask = TASK_LF;
			cModule = &LFSys;
		break;

		// -- OBJECT HANDLING --
		case TASK_OBJ:
			currentTask = TASK_LF;
			cModule = &LFSys;
		break;
		}
}

int main() {

	// Pull-Ups for the TWI system
	PORTC |= (0b11 << 4);

	cModule = &LFSys;

	System.Motor.setRotationSpeed(50);

	servo.setServo(255);

	_delay_ms(500);

	while(true) {
		setTask();

		cModule->execute();
	}

	return 0;
}

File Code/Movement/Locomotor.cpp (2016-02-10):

/*
 * Locomotor.cpp
 *
 *  Created on: Nov 11, 2015
 *      Author: xasin
 */

#include "Locomotor.h"
#include <util/delay.h>

//Constructor of the Locomotor object
Locomotor::Locomotor(TranslativeStepper *A, TranslativeStepper *B,
		TranslativeStepper *C, uint16_t ISRFreq) {
	this->A = A;
	this->B = B;
	this->C = C;

	this->ISRFreq = ISRFreq;

}

//Recalculate X and Y speed factors.
void Locomotor::recalculateXYFact() {
	ATOMIC_BLOCK(ATOMIC_FORCEON)
	{
		float travelMM = sqrt(
				pow((this->xTarget - this->xPos), 2)
						+ pow(this->yTarget - this->yPos, 2)); //Calculate the distance the robot has to travel.

						//Calculate the X and Y factors (basically sinus and cosinus values for current direction of travel)
		this->xFact = ((this->xTarget - this->xPos) / travelMM);
		this->yFact = ((this->yTarget - this->yPos) / travelMM);
	}
}

void Locomotor::setRotationSpeed(float newSpeed) {
	ATOMIC_BLOCK(ATOMIC_FORCEON)
	{
		this->rPerISR = fabs(newSpeed) / this->ISRFreq;
	}
}

void Locomotor::setSpeed(float newSpeed) {
	ATOMIC_BLOCK(ATOMIC_FORCEON)
	{
		if (newSpeed > 1) {
			this->speedTarget = newSpeed / ISRFreq;
		}
	}
}

void Locomotor::setAcceleration(float acceleration) {
	ATOMIC_BLOCK(ATOMIC_FORCEON)
	{
		if (acceleration > 0)
			this->acceleration = acceleration / ISRFreq / ISRFreq;
	}
}

void Locomotor::moveTo(float x, float y) {
	ATOMIC_BLOCK(ATOMIC_FORCEON)
	{
		this->xTarget = x;
		this->yTarget = y;

		this->recalculateXYFact();
	}
}

void Locomotor::moveBy(float x, float y) {
	ATOMIC_BLOCK(ATOMIC_FORCEON)
	{
		this->xTarget += x;
		this->yTarget += y;

		this->recalculateXYFact();
	}
}

void Locomotor::moveTowards(float dist) {
		this->moveTowards(dist, this->rPos);
}

void Locomotor::moveTowards(float dist, float dir) {
	ATOMIC_BLOCK(ATOMIC_FORCEON)
	{
		this->xTarget += dist * cos(dir * DEG_TO_RAD);
		this->yTarget += dist * sin(dir * DEG_TO_RAD);

		this->recalculateXYFact();
	}
}

void Locomotor::flush() {
	do {
		_delay_ms(10);
	} while (!this->isReady());
}

void Locomotor::update() {

	//Pre-Calculate the Sin and Cos values for the current INVERSE Rotation!!
	float cSin = sin(-1 * this->rPos * DEG_TO_RAD);
	float cCos = cos(-1 * this->rPos * DEG_TO_RAD);

	//Calculate the steps that the motors will have to do this calculation. CAUTION - X and Y Motor axis do not aling with the Robot's current X and Y Axis!
	float xDifference = this->xTarget - this->xPos;
	float yDifference = this->yTarget - this->yPos;
	float rDifference = this->rTarget - this->rPos;
	float speedDiff = this->speedTarget - this->speed; //Calculate the speed difference (target to current speed)

	//How much will the robot have to move each calculation?
	float xThisISR = 0;
	float yThisISR = 0;
	float rThisISR = 0;

	/* --- Basic explanation of the calculation ---
	 * if the motor has to do any movement in the specified direction
	 * Calculate how much movement it will have to do in this ISR. This is either the currently set speed, calculated from the Axis-Speed-Factor and current robot speed,
	 * or the remaining distance between target and current position, whatever is smaller.
	 * Then increase (or decrease) the current position by the amount of mm that the robot will move this ISR.
	 */

	//Speed recalcultion
	if (speedDiff != 0)
		this->speed += (
				(fabs(speedDiff) > this->acceleration) ?
						((speedDiff > 0) ?
								this->acceleration : -this->acceleration) :
						speedDiff);

	//X-Steps calculation
	if (xDifference != 0) {
		xThisISR =
				(fabs(xDifference) > fabs(this->xFact * speed)) ?
						xFact * speed : xDifference;
		this->xPos += xThisISR;
	}

	//Y-Steps calculation
	if (yDifference != 0) {
		yThisISR =
				(fabs(yDifference) > fabs(this->yFact * speed)) ?
						yFact * speed : yDifference;
		this->yPos += yThisISR;
	}

	//Rotation-Stepping calculation
	if (rDifference != 0) {
		rThisISR =
				(fabs(rDifference) > fabs(this->rPerISR)) ?
						((rDifference < 0) ? -rPerISR : rPerISR) : rDifference;
		this->rPos += rThisISR;
	}

	//Rotate the movement axis.
	//As mentioned before, this is due to the ROBOT AXIS != MOTOR-RELATIVE AXIS
	float xRotated = cCos * xThisISR - cSin * yThisISR;
	float yRotated = cSin * xThisISR + cCos * yThisISR;

	A->stepBy(xRotated, yRotated, rThisISR);
	B->stepBy(xRotated, yRotated, rThisISR);
	C->stepBy(xRotated, yRotated, rThisISR);

	//Reset acceleration if at target and not having received a new command for ACCEL_DEBOUNCE_CYCLES updates
	if (this->atPosition()) {
		if (accelDebounce == 0)
			this->speed = 0;
		else
			accelDebounce--;
	} else
		accelDebounce = ACCEL_DEBOUNCE_CYCLES;

	//Make sure the rotation values do not get too high
	if (this->rPos > 360) {
		this->rPos -= 360;
		this->rTarget -= 360;
	}
	else if(this->rPos < -360) {
		this->rPos += 360;
		this->rTarget += 360;
	}
}

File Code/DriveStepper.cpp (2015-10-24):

/*
 * DriveStepper.cpp
 *
 *  Created on: 08.10.2015
 *      Author: xasin
 */

#include "DriveStepper.h"
#include <util/delay.h>

DriveStepper::DriveStepper(volatile uint8_t *P, uint8_t pin,
		uint16_t updateFrequency, uint16_t calculationFrequency,
		float stepsPerMM, float motorOffset, float localRotation) {
	ATOMIC_BLOCK(ATOMIC_FORCEON)
	{
		//Initialize all the values.
		this->PORT = P;
		this->pin = pin;
		this->updateFrequency = updateFrequency;
		this->ISRPerCal = updateFrequency / calculationFrequency;
		this->stepsPerMM = stepsPerMM;
		this->motorOffset = motorOffset;
		this->localRotation = localRotation;

		//Enable output mode
		*(PORT - 1) |= (0b11 << pin);

		//Set absolute position values to 0.
		currentRotation = 0;
		currentX = 0;
		currentY = 0;

		//Set the software prescaler value to 0.
		calculationDivider = 0;
	}
}

void DriveStepper::recalSinCos(float angle) {
	if (angle != oldAngle) {
		currentSin = sin(angle);
		currentCos = cos(angle);

		oldAngle = angle;
	}
}

void DriveStepper::recalculate() {
	//Software prescaler
	if (++calculationDivider == ISRPerCal) {
		calculationDivider = 0;

		if (currentX != targetX) {
			if (fabs(targetX - currentX) >= fabs(xPerCal)) {
				recalSinCos((currentRotation + localRotation) * DEG_TO_RAD);

				/*//Step the motor by the according amount.*/
				stepsToGo += currentSin * xPerCal * stepsPerMM;

				//Shift the current position by what we will move.
				currentX += xPerCal;
			} else {
				stepsToGo += currentSin * (targetX - currentX) * stepsPerMM;

				currentX = targetX;
			}
		}

		if (currentY != targetY) {
			recalSinCos((currentRotation + localRotation) * DEG_TO_RAD);
			if (fabs(targetY - currentY) >= fabs(yPerCal)) {

				stepsToGo += currentCos * yPerCal * stepsPerMM;

				currentY += yPerCal;
			} else {
				stepsToGo += currentCos * (targetY - currentY) * stepsPerMM;

				currentY = targetY;
			}
		}

		stepSpeed = fabs(stepsToGo / (ISRPerCal));
	} else if (calculationDivider == ISRPerCal / 2) {

		if (fabs(targetRotation - currentRotation) >= fabs(degPerCal)) {
			if ((targetRotation - currentRotation) < 0) {
				currentRotation -= degPerCal;

				stepsToGo -= motorOffset * (degPerCal * DEG_TO_RAD)
						* stepsPerMM;
			} else {
				currentRotation += degPerCal;

				stepsToGo += motorOffset * (degPerCal * DEG_TO_RAD)
						* stepsPerMM;
			}
		}

		stepSpeed = fabs(stepsToGo / (ISRPerCal));
	}
}

void DriveStepper::moveXYBy(float X, float Y) {
	float totalMM = sqrt(pow(X, 2) + pow(Y, 2));

	ATOMIC_BLOCK(ATOMIC_FORCEON)
	{
		targetX += X;
		targetY += Y;
		xPerCal = X / ((totalMM / mmPerSec) * (updateFrequency / ISRPerCal));
		yPerCal = Y / ((totalMM / mmPerSec) * (updateFrequency / ISRPerCal));
	}
}

void DriveStepper::moveXYTo(float X, float Y) {
	float totalMM = sqrt(pow((currentX - X), 2) + pow(currentY - Y, 2));

	ATOMIC_BLOCK(ATOMIC_FORCEON)
	{
		targetX = X;
		targetY = Y;
		xPerCal = X / ((totalMM / mmPerSec) * (updateFrequency / ISRPerCal));
		yPerCal = Y / ((totalMM / mmPerSec) * (updateFrequency / ISRPerCal));
	}
}

void DriveStepper::rotateTo(float angle) {
	ATOMIC_BLOCK(ATOMIC_FORCEON)
	{
		this->targetRotation = angle;
	}
}

void DriveStepper::rotateBy(float angle) {
	ATOMIC_BLOCK(ATOMIC_FORCEON)
	{
		this->targetRotation += angle;
	}
}

void DriveStepper::finishRotation() {
	while ((currentRotation - targetRotation) != 0) {
		_delay_ms(1);
	}
}

void DriveStepper::finishMovement() {
	while ((currentX - targetX) != 0 || (currentY - targetY) != 0) {
		_delay_ms(1);
	}
}

void DriveStepper::finishAll() {
	finishMovement();
	finishRotation();
}

void DriveStepper::setRotationSpeed(float degPerSec) {
	ATOMIC_BLOCK(ATOMIC_FORCEON)
	{
		this->degPerCal = degPerSec / (updateFrequency / ISRPerCal);
	}
}

void DriveStepper::setMovementSpeed(float mmPerSec) {
	ATOMIC_BLOCK(ATOMIC_FORCEON)
	{
		this->mmPerSec = mmPerSec;
	}
}

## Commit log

2010-01-01 Changed drive preference to move along right, not left.
    [Main.sch]
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2015-09-16 First Github Repo Push!! Oh, and added a README.
    [HexGrid.scad]
2015-09-16 There we go. Actual Commit, including all the files (instead of empty push *sigh*)
    [HexGrid.scad, HexGrid.stl]
2015-09-16 Moved the OpenSCAD "Transforms.scad" Library into the repo.
    [HexGrid.scad, Transforms.scad]
2015-09-16 Removed that one weird HexGrid.scad directly in the master directory. Why.
    [HexGrid.scad]
2015-09-17 Added the first (and hopefully last) version of the .scad file used for creating the subwheels of a Omni-wheel. All functions are commented, no need for later commenting.
    [OmniWheel.scad]
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2015-09-17 Fine-tuned the Filament-Axis holes.
    Values are now: 2.25 for tight-fitting and 2.4 for loosely-fitting.
    [OmniWheel.scad]
2015-09-17 Finalised the wheels. Fixes #1
    [OmniWheel.scad]
2015-09-18 Fixed the center piece of the OmniWheels.
    It not resizes properly, making itself fit nicely.
    Recommended wheel sizes: 20mm, 4 pieces or 30mm with 5 pieces
    [OmniWheel.scad]
2015-09-19 Filament axis hole now is only tighter towards end of the wheel.
    This should make it much more easy to insert the filament and fix the wheels in place. Glue is still recommended.
    Also, the hole diameter now is designed for toothpicks!!!
    [OmniWheel.scad]
2015-09-19 Fine-tuned axis-hole-size
    Small improvements, nothing worth mentioning for now.
    [OmniWheel.scad]
2015-09-20 Optimised and changed a few things.
    Nothing worth noting, mostly making the holes more fitting!
    [OmniWheel.scad]
2015-09-20 Complete redesign of the OmniWheel
    [HexGrid.scad, OmniWheel.scad]
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2015-09-20 Tweaked the Design more. TODO!!
    The current design is not yet finished!
    Adjustments have to be made to attach the subwheels!
    [OmniWheel.scad]
2015-09-20 Minor tweaks to the subwheel "Inflated" mode for subtractions
    [OmniWheel.scad]
2015-09-21 Finalised the alternate design!
    Added connectors for the subwheels, changed up the center piece a bit to use up less filament and all that.
    [OmniWheel.scad]
2015-09-22 SO Much less Filament.
    Changed the model to use a LOT less filament, also reducing priting time.
    Basically made everything hollow and added small strucutral beams.
    Oh, and comments. Comments and more comments.
    [OmniWheel.scad]
2015-09-23 Complete redesign! My gosh, everything has changed. The central cylinder now is split into two symmetric parts that have to be glued together This SHOULD fix printing problems and allow for connector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
    [OmniWheel.scad]
2015-09-23 Changed up structure.
    Added comments to most of the lines (Yay)
    Also changed up the system to have outside connectors, have two separated halves, finalised some edges etc. etc.
    [OmniWheel.scad]
2015-09-25 Redid the Center piece code, much cleaner now.
    Redid lots of things, most noticably the center piece.
    This also includes stuff and configurability. Lots of things were replaced by variables and should be MUCH easier to configure now.
    [OmniWheel.scad]
2015-09-26 Finalisation!
    This is it! Final version of the OmniWheels!
    The Subwheels connect firmly and roll well from every angle. The center pieces can be clicked together with ease!
    The code is cleaned up and commented, and everything important should be able to be modified on the fly with the variables.
    Merging to master!
    [OmniWheel.scad]
2015-09-26 Even more cleanup! Made sure that all important configurables are reachable at the top of the file through lovely variables. Everything can be changed, so the wheel now is customizable for any needs!
    [OmniWheel.scad]
2015-09-26 Even more configurability! Seriously, round about now almost everything can be configured with a variable. //No warnings will be issued if the variables are set wrong!! //
    [OmniWheel.scad]
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2015-09-27 Added subwheel overlap value. This should allow for smoother running, as the subwheels overlap for a short amount of time, allowing the wheels to have a smoother run.
    [OmniWheel.scad]
2015-09-29 Final changes, small tweaks and whatnot. We are preparing for the absolute final version of the Omni-Wheel, which means that I am working on perfecting the settings. Not many more code improvements s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
    [OmniWheel.scad]
2015-10-01 First improvements on the Hexagonal Structure system!
    Made a few things accessible through variables, will change up the actual values and stuff later on.
    [HexGrid.scad]
2015-10-03 Added the first bits of code to the system!
    Right now it's just a LCD Display driver, however after this I should start to get to work on my actual calculations!
    [HexGrid.scad]
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2015-10-05 Fixed all the header files!
    Oh, and a bit of playing around with the LED PWM code and first tests of the smart lighting.
    It's gonna look great :3
    [main.cpp]
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2015-10-07 Improvements to the ISR Step speed calculation.
    I still have to play around with the system to find out the best way to calculate and step the motors.
    Right now it fails to go over a specific amount (ISR Frequency < Stepping speed), but this can be resolved by making the ISR faster.
    [PrimitiveStepper.cpp, RotaryStepper.cpp]
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2015-10-08 Fixed and finished the relative X and Y movements.
    The current calculations manage everything required for this movement.
    However, code can and will be optimised for ISR constant mixed calculations.
    [DriveStepper.cpp, main.cpp]
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2015-10-15 Untested optimisations for mov. cal and refined and strenghtened OmniWheel Bases.
    [OmniWheel.scad]
2015-10-24 Completed the stepper motor holder for the HexGrid robot system.
    [HexGrid.scad, OmniWheel.scad, StepperMotorHolder.scad]
2015-10-24 Small fix for the Stepper Motor connecting plate (size)
    [StepperMotorHolder.scad]
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2015-10-25 Complete rewrite of the hexgrid System for flexibility reasons.
    [NewHexGrid.scad]
2015-10-25 Fixes to the new hexgrid system
    [NewHexGrid.scad]
2015-10-26 Updated a few size values and fine tuned distances.
    [NewHexGrid.scad, StepperMotorHolder.scad]
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2015-11-19 Began redesigning the motor hex system, added base-plate with integrated motor holder.
    [MotorPlate.scad, NewHexGrid.scad]
2015-11-19 First steps towards the base plate design, also changed the way that "beamPlay" affects the model to a sloped bottom piece.
    [MotorPlate.scad, NewHexGrid.scad]
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2015-11-21 Tried to fix the hexGrid system, and kinda managed that + First attempt at the base plate.
    [MotorPlate.scad, StepperMotorHolder.scad]
2015-11-21 Small change to clean up the code structure.
    [MotorPlate.scad, NewHexGrid.scad, Transforms.scad]
2015-11-21 Comments. Lots of them. And a clearer, cleaner code. Finally.
    [MotorPlate.scad]
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2015-11-22 Small fixes to the stepper motor system.
    [TranslativeStepper.cpp, main.cpp]
2015-11-22 Small fix to properly include Motor C
    [main.cpp]
2015-11-22 Small rework of the hex grid structure to make it a bit more printable.
    [MotorPlate.scad]
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2015-11-22 Small clean-up and changes to the 3D Model file structure
    [NewHexGrid.scad, OmniWheel.scad, StepperMotorHolder.scad]
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2015-11-25 Fixed a small comparison bug in Locomotor update class. Also, first successful test!
    [Locomotor.cpp, main.cpp]
2015-11-27 Small important fix to the XY-Coordinate to TranslativeStepper-Coordinate calculation
    [Locomotor.cpp, main.cpp]
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2015-11-28 First implementation of a intermediate layer & distancer
    [BasePlate.scad, Distancer.scad]
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2015-12-03 Added a LF Sensor mount for the System.
    [LF-Senor-Mount.scad]
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2015-12-05 Finished inclusion of I2CHandler, new issue
    [main.cpp]
2015-12-05 Implementation of a electronics holder and other various fixes
    [ControllerHolder.scad, Distancer.scad, LF-Senor-Mount.scad]
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2015-12-09 Correcting some small values
    [main.cpp]
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2015-12-11 Fixes to the LF Sensor mounting kit, plus shielding.
    [LF-Senor-Mount.scad, MotorPlate.scad]
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2015-12-12 Finally fixed the I2C Constr.
    [main.cpp]
2015-12-13 +Smaller fixes +Added comments and port specifications -Deleted led support (cleaned up)
    [ColorRecognitionsensor_ArduinoVersion_.ino]
2015-12-13 *Fixed "red-bug" by tweaking rgb values
    [ColorRecognitionsensor_ArduinoVersion_.ino]
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2015-12-14 Probably unncecesary fixes to some values
    [LF-Sensor-Mount.scad, LF-Sensor-Shielding.scad]
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2015-12-20 Slave addressing works now! Fixed the accidental Write Collosion bug, in which TWINT was cleared prematurely
    [main.cpp]
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2016-01-03 First verion of a proper LF Class This new class system should make working with Line Following much easier, as the interfacing functions will always stay the same. This allows for more changes to be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
    [LFBasic.h]
2016-01-03 +Added the colour black to the programm *Tweaked the other colours a little to avoid overlapping
    [ColorRecognitionsensor_ArduinoVersion_.ino]
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2016-01-13 Changed a var to be initialised and volatile. Seems to have fixed the codegit push
    [LFBasic.h, main.cpp]
2016-01-13 Added ATOMIC BLOCK in Stepper constructor to prevent collisions
    [TranslativeStepper.cpp, main.cpp]
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2016-01-25 Fixed LFFollow speed setting
    [LFFollow.cpp]
2016-02-03 Value tweaking and minor code fixing
    [LFFollow.cpp, LFFollow.h]
2016-02-03 Fixed TranslativeStepper ISRPerCal calculation
    [LFFollow.cpp, LFFollow.h, main.cpp]
2016-02-03 Starting tweaks to find BUG 'SUDDEN STOP'
    [Intersection.cpp, LFFollow.h, main.cpp]
2016-02-06 Added a new sensor mounting system (Because the old one is shit)
    [SensorMount.scad]
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2016-02-06 Added a piece of code to secure the rotation (might get too large otherwise)
    [Locomotor.cpp]
2016-02-07 Fixes #7 - Stopping bug Changed the code for 'At position' and 'At rotation' slightly, rounding the values down to remove error through the floating commas
    [LFFollow.cpp, Locomotor.cpp]
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2016-02-08 Started design for a touch sensor mount :3
    [BoopSensor.scad]
2016-02-09 Tweaked the boop sensor holder a bit. Works! Yay!
    [BoopSensor.scad]
2016-02-09 Added the Object Avoidance module, yay! :D
    [ObjectAvoid.cpp]
2016-02-10 Started fine-tuning the avoidance system
    [Locomotor.cpp, ObjectAvoid.cpp]
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2016-02-16 Added the object avoidance into normal code sequence!
    [main.cpp]
2016-02-17 Fine-Tuned (and fixed) LFSensor capture delay
    [LFFollow.cpp, LFFollow.h, main.cpp]
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2016-02-19 Finalised the scematics, and started working on a PCB!
    [Main.kicad_pcb, Main.sch]
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2016-02-20 Added battery holder models! TODO - Size them correctly.
    [BHolder.fcstd, Base.scad]
2016-02-21 Changed the battery holder to fit the battery!
    [BHolder.fcstd]
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2016-02-22 Removed different speed settings. Too slow otherwise.
    [Intersection.cpp]
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2016-02-23 Tweaked the object avoidance code :3
    [ObjectAvoid.cpp]
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2016-03-08 Fixed a bug in the 'searchJobs' func. TWI now tested & MT works.
    [main.cpp]
2016-03-08 Added proper error handling for TWI_Handler
    [main.cpp]
2016-03-08 Trying to fix a Repeated Start problem.
    [main.cpp]
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2016-03-12 Fixed the TWI connections.
    [Sensor.sch]
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2016-03-14 Changed the board layout and added a diagnostic LED and a PWM pin.
    [Sensor.kicad_pcb, Sensor.sch]
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2016-04-12 Tiny adjust to the HexGrid library, as well as addition of a sensor chip mount!
    [SensorControllerHolder.scad]
2016-04-12 Made the device holder a little thicker for more stability!
    [SensorControllerHolder.scad]
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2016-04-16 New bug: TWI System 'blocking' when having multiple jobs close-up.
    [main.cpp]
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2016-04-23 Bit-Shifting fix (from 1 to 2 (10b to 8b conversation)
    [BrightSensor.cpp]
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2016-04-24 Typo fixing. NEEDS CHECK - L8 Night
    [ADC_Lib.cpp, main.cpp]
2016-04-25 Fixed ADC_Lib 'selectNextPin()' function
    [ADC_Lib.cpp]
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2016-04-27 Fixed behavior of the ACD_Lib for measuring multiple inputs
    [ADC_Lib.cpp]
2016-04-27 Fixed setting the touch sensor as output, thusly reduces heating
    [main.cpp]
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2016-04-27 Added a middle light blockade to prevent self-lighting issues and made walls thicker.
    [BSensorShielding.scad]
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2016-04-28 Made the sensor mounts a tiny bit more sturdy, and more pretty.
    [SensorMount.scad]
2016-04-28 Tweaked the object avoidance code a bit to make sure that it complies (a tiny bit) with the sideways shifting of the robot
    [ObjectAvoid.cpp]
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2016-04-28 Reimplementation of the old movement habit (LF and avoidance)
    [main.cpp]
2016-04-29 Removed the rotations in the whole object avoidance thingy again. Wasn't all that necessary.
    [ObjectAvoid.cpp, main.cpp]
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2016-04-30 Added a variable-direction object avoiding code.
    [ObjectAvoid.cpp]
2016-04-30 Changed the distance for the object avoidance code.
    [ObjectAvoid.cpp]
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
